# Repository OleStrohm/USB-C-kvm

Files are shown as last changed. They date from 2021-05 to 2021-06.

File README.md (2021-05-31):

# USB C kvm
A USB C kvm used to switch one output connection between two input connections.

This allows one to connect a peripheral to the output and a computer to each
input, and then switch which computer it should be connected to with the press
of a button.

## Goals
These are the design goals I'm aiming for:

* Full speed USB C including PD.
* Cheap and robust implementation
* SMD, but solderable by hand.

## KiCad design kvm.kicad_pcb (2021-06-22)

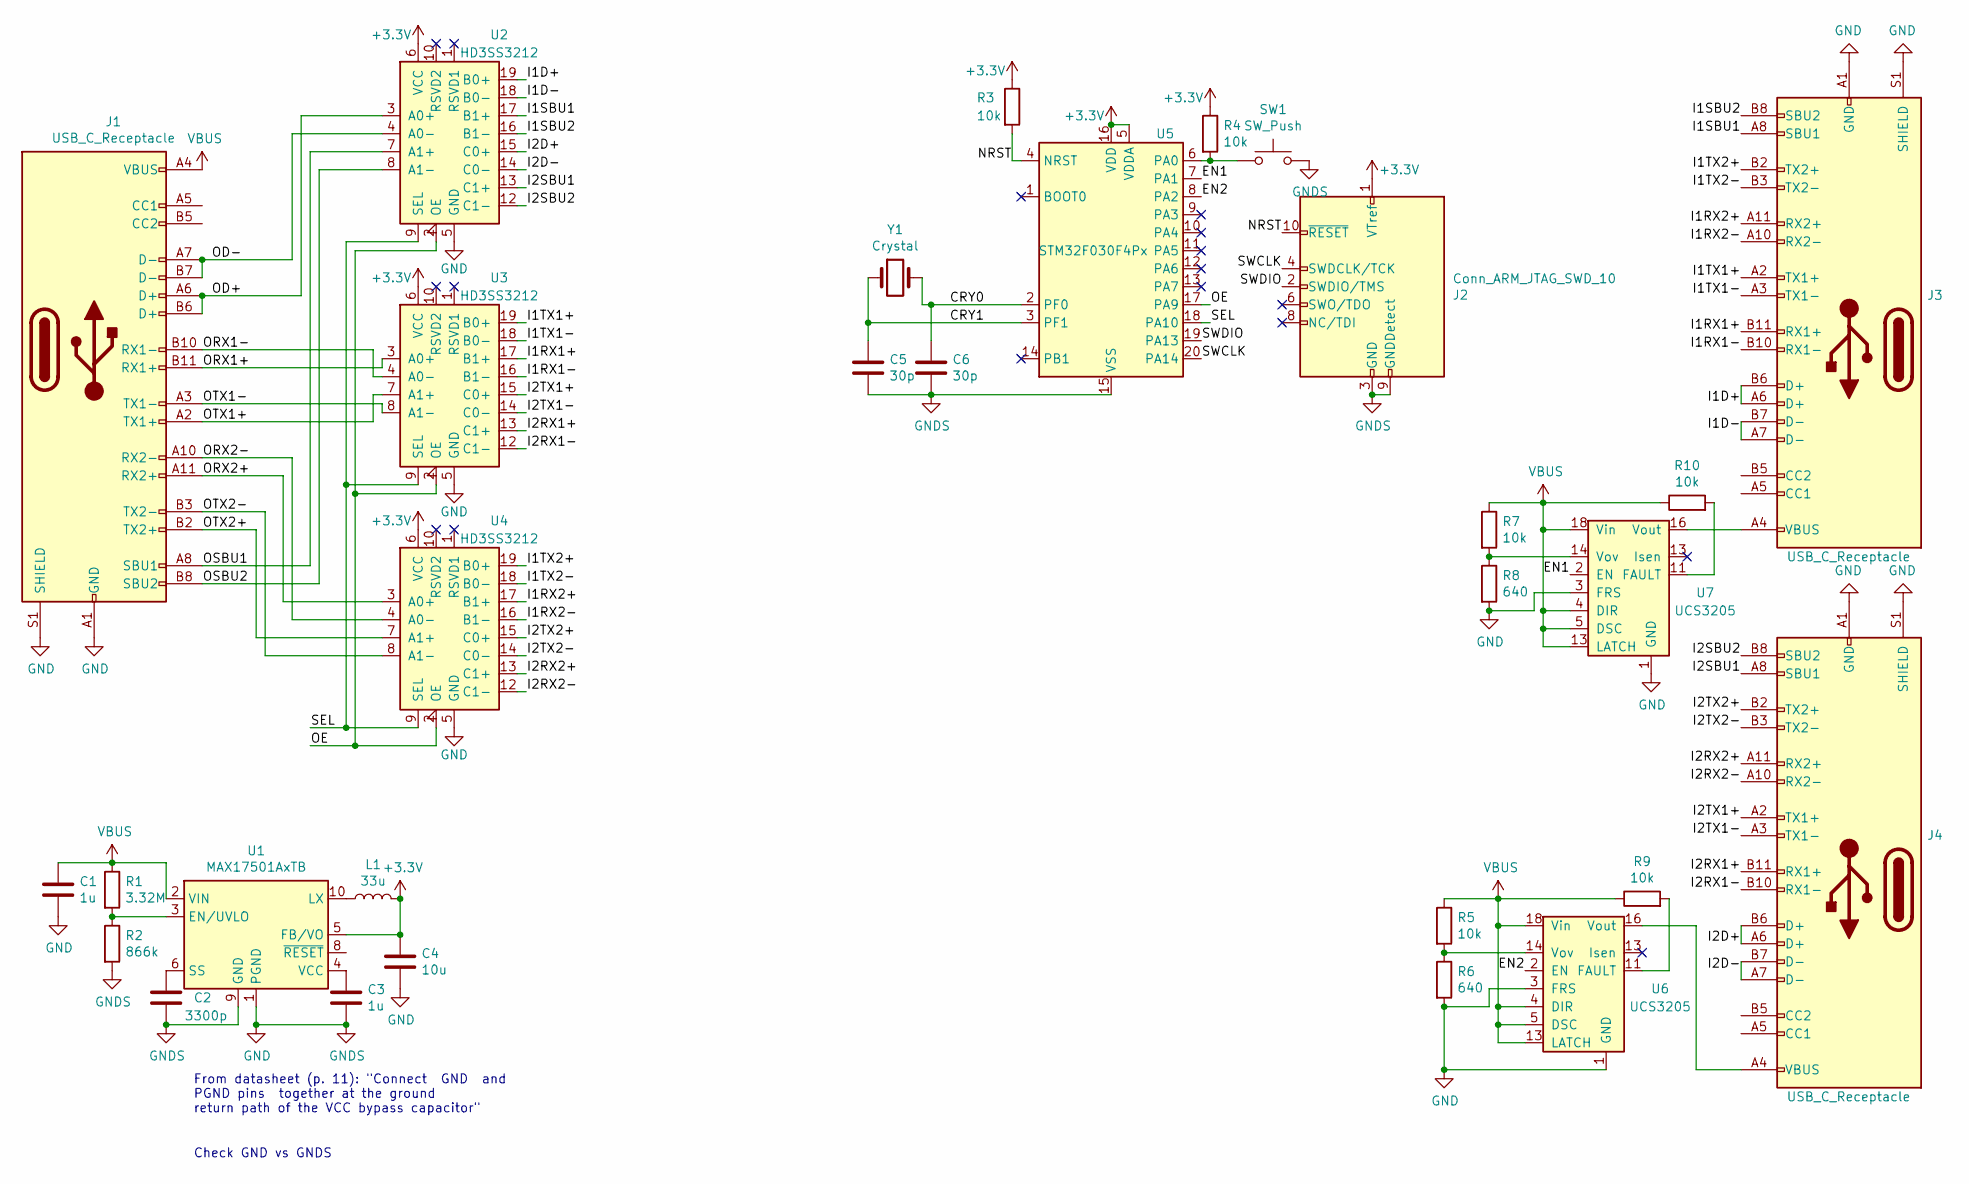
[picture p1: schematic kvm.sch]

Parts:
C1, C3: 1u; C_0805_2012Metric
C2: 3300p; C_0805_2012Metric
C4: 10u; C_1206_3216Metric
C5, C6: 30p; C_0805_2012Metric
J1, J3, J4: USB_C_Receptacle; USB_C_Receptacle_Amphenol_12401548E4-2A
J2: Conn_ARM_JTAG_SWD_10; PinHeader_2x05_P1.27mm_Vertical_SMD
L1: 33u; L_0805_2012Metric
R1: 3.32M; R_0805_2012Metric
R2: 866k; R_0805_2012Metric
R3, R4, R5, R7, R9, R10: 10k; R_0805_2012Metric
R6, R8: 640; R_0805_2012Metric
SW1: SW_Push; SW_SPST_B3S-1000
U1: MAX17501AxTB; TDFN-10-1EP_2x3mm_P0.5mm_EP0.9x2mm
U2, U3, U4: HD3SS3212; VQFN20RKS
U5: STM32F030F4Px; TSSOP-20_4.4x6.5mm_P0.65mm
U6, U7: UCS3205; VQFN19_3x3x0.9mm
Y1: Crystal; Crystal_HC49-4H_Vertical

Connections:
+3V3: C4.1, J2.1 (VTref), L1.2, R3.1, R4.1, U1.5 (FB/VO), U2.6 (VCC), U3.6 (VCC), U4.6 (VCC), U5.5 (VDDA), U5.16 (VDD)
/CRY0: C6.1, U5.2 (PF0), Y1.2
/CRY1: C5.1, U5.3 (PF1), Y1.1
/EN1: U5.7 (PA1), U7.2 (EN)
/EN2: U5.8 (PA2), U6.2 (EN)
/I1D+: J3.A6 (D+), J3.B6 (D+), U2.19 (B0+)
/I1D-: J3.A7 (D-), J3.B7 (D-), U2.18 (B0-)
/I1RX1+: J3.B11 (RX1+), U3.17 (B1+)
/I1RX1-: J3.B10 (RX1-), U3.16 (B1-)
/I1RX2+: J3.A11 (RX2+), U4.17 (B1+)
/I1RX2-: J3.A10 (RX2-), U4.16 (B1-)
/I1SBU1: J3.A8 (SBU1), U2.17 (B1+)
/I1SBU2: J3.B8 (SBU2), U2.16 (B1-)
/I1TX1+: J3.A2 (TX1+), U3.19 (B0+)
/I1TX1-: J3.A3 (TX1-), U3.18 (B0-)
/I1TX2+: J3.B2 (TX2+), U4.19 (B0+)
/I1TX2-: J3.B3 (TX2-), U4.18 (B0-)
/I2D+: J4.A6 (D+), J4.B6 (D+), U2.15 (C0+)
/I2D-: J4.A7 (D-), J4.B7 (D-), U2.14 (C0-)
/I2RX1+: J4.B11 (RX1+), U3.13 (C1+)
/I2RX1-: J4.B10 (RX1-), U3.12 (C1-)
/I2RX2+: J4.A11 (RX2+), U4.13 (C1+)
/I2RX2-: J4.A10 (RX2-), U4.12 (C1-)
/I2SBU1: J4.A8 (SBU1), U2.13 (C1+)
/I2SBU2: J4.B8 (SBU2), U2.12 (C1-)
/I2TX1+: J4.A2 (TX1+), U3.15 (C0+)
/I2TX1-: J4.A3 (TX1-), U3.14 (C0-)
/I2TX2+: J4.B2 (TX2+), U4.15 (C0+)
/I2TX2-: J4.B3 (TX2-), U4.14 (C0-)
/NRST: J2.10 (~RESET~), R3.2, U5.4 (NRST)
/OD+: J1.A6 (D+), J1.B6 (D+), U2.3 (A0+)
/OD-: J1.A7 (D-), J1.B7 (D-), U2.4 (A0-)
/OE: U2.2 (OE), U3.2 (OE), U4.2 (OE), U5.17 (PA9)
/ORX1+: J1.B11 (RX1+), U3.3 (A0+)
/ORX1-: J1.B10 (RX1-), U3.4 (A0-)
/ORX2+: J1.A11 (RX2+), U4.3 (A0+)
/ORX2-: J1.A10 (RX2-), U4.4 (A0-)
/OSBU1: J1.A8 (SBU1), U2.7 (A1+)
/OSBU2: J1.B8 (SBU2), U2.8 (A1-)
/OTX1+: J1.A2 (TX1+), U3.7 (A1+)
/OTX1-: J1.A3 (TX1-), U3.8 (A1-)
/OTX2+: J1.B2 (TX2+), U4.7 (A1+)
/OTX2-: J1.B3 (TX2-), U4.8 (A1-)
/SEL: U2.9 (SEL), U3.9 (SEL), U4.9 (SEL), U5.18 (PA10)
/SWCLK: J2.4 (SWDCLK/TCK), U5.20 (PA14)
/SWDIO: J2.2 (SWDIO/TMS), U5.19 (PA13)
GND: C1.2, C2.2, C3.2, C4.2, C5.2, C6.2, J1.A1 (GND), J1.A12 (GND), J1.B1 (GND), J1.B12 (GND), J1.S1 (SHIELD), J2.3 (GND), J2.5 (GND), J2.9 (GNDDetect), J3.A1 (GND), J3.A12 (GND), J3.B1 (GND), J3.B12 (GND), J3.S1 (SHIELD), J4.A1 (GND), J4.A12 (GND), J4.B1 (GND), J4.B12 (GND), J4.S1 (SHIELD), R2.2, R6.2, R8.2, SW1.2, U1.1 (PGND), U1.9 (GND), U1.11 (GND), U2.0 (GND), U2.5 (GND), U2.11 (GND), U2.20 (GND), U3.0 (GND), U3.5 (GND), U3.11 (GND), U3.20 (GND), U4.0 (GND), U4.5 (GND), U4.11 (GND), U4.20 (GND), U5.15 (VSS), U6.1 (GND), U6.3 (FRS), U6.15 (GND), U7.1 (GND), U7.3 (FRS), U7.15 (GND)
unnamed: C2.1, U1.6 (SS)
unnamed: C3.1, U1.4 (VCC)
unnamed: J3.A4 (VBUS), J3.A9 (VBUS), J3.B4 (VBUS), J3.B9 (VBUS), U7.16 (Vout), U7.17 (Vout), U7.21 (Vout)
unnamed: J4.A4 (VBUS), J4.A9 (VBUS), J4.B4 (VBUS), J4.B9 (VBUS), U6.16 (Vout), U6.17 (Vout), U6.21 (Vout)
unnamed: L1.1, U1.10 (LX)
unnamed: R1.2, R2.1, U1.3 (EN/UVLO)
unnamed: R4.2, SW1.1, U5.6 (PA0)
unnamed: R5.2, R6.1, U6.14 (Vov)
unnamed: R7.2, R8.1, U7.14 (Vov)
unnamed: R9.2, U6.11 (FAULT)
unnamed: R10.2, U7.11 (FAULT)
VBUS: C1.1, J1.A4 (VBUS), J1.A9 (VBUS), J1.B4 (VBUS), J1.B9 (VBUS), R1.1, R5.1, R7.1, R9.1, R10.1, U1.2 (VIN), U6.4 (DIR), U6.5 (DSC), U6.13 (Isen), U6.18 (Vin), U6.19 (Vin), U6.20 (Vin), U7.4 (DIR), U7.5 (DSC), U7.13 (Isen), U7.18 (Vin), U7.19 (Vin), U7.20 (Vin)

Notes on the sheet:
From datasheet (p. 11): "Connect GND and PGND pins together at the ground return path of the VCC bypass capacitor"
Check GND vs GNDS

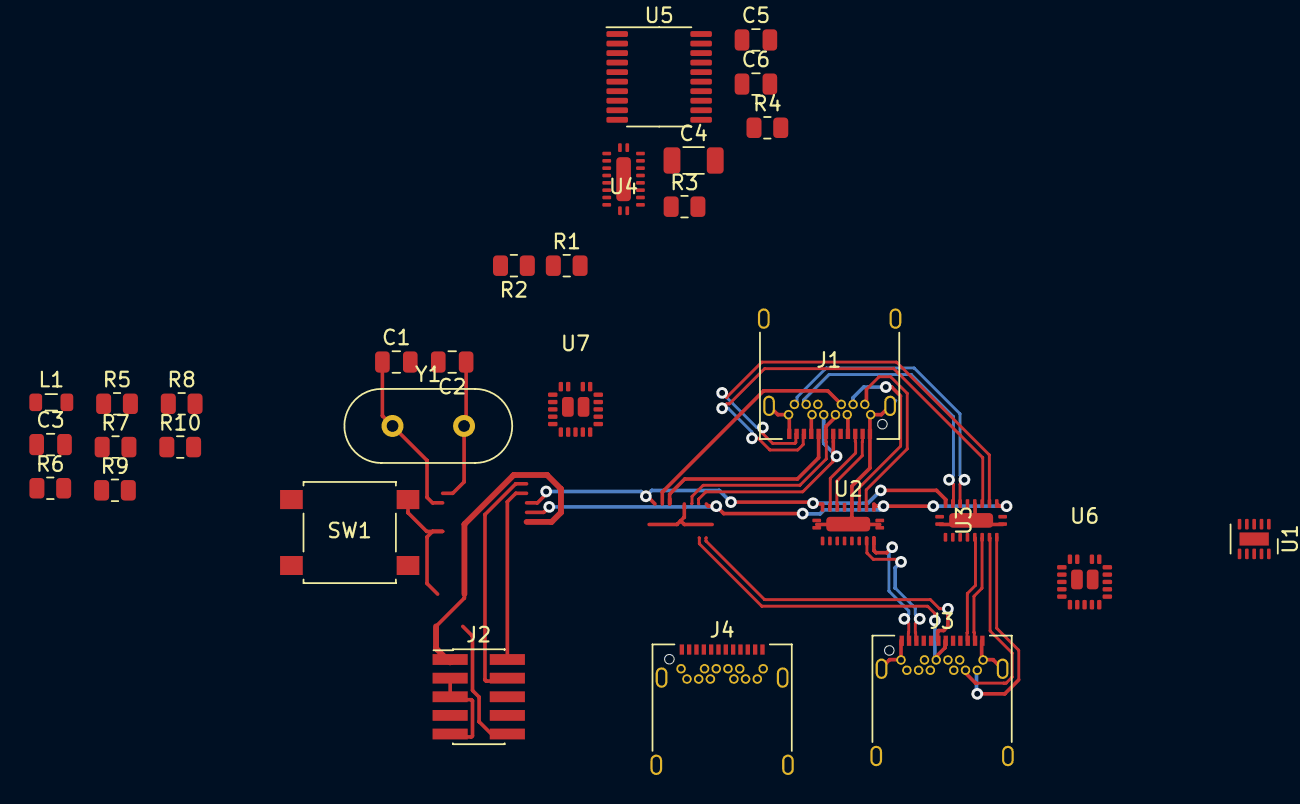
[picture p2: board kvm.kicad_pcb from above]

Board: 4 copper layers, 30 parts (0 on the bottom side), 59 nets.

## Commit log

2021-05-31 Initial commit
    Almost got the data switching working. Power and control ciruit is
    unimplemented.
    [kvm.kicad_pcb, kvm.sch]
2021-06-11 Added a micro controller and SWD header
    [kvm.kicad_pcb, kvm.sch]
2021-06-18 Added a power buffer on VBus
    [kvm.sch]
2021-06-22 finished PD switches and added 3.3V PSU
    [kvm.kicad_pcb, kvm.sch]
2021-06-23 Added PD, maybe finished v1!
    [kvm.sch]
2021-06-24 Fixed errors in component schematics and added decoupling caps
    [kvm.sch]
2021-10-11 Added separate power input for control circuit
    [kvm.sch]
2021-10-11 Added annotations
    [kvm.sch]
